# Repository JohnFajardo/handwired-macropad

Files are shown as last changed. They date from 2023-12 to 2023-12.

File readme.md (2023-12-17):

# Handwired Macropad

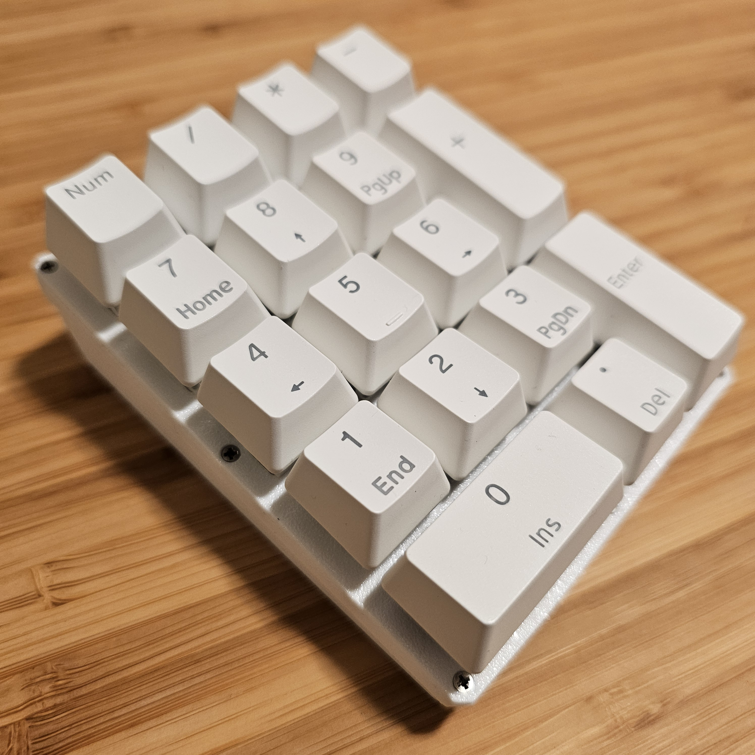
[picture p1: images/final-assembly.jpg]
final assembly


A quick handwired macropad I built for a coworker so that he could sample Box Jade switches.

## Bill of materials
* 17 Cherry style, plate-mounted switches, for example [Kailh Box Jades](https://www.amazon.com/gp/product/B0CBPRMP27/).

* 17 numpad keycaps salvaged from [el cheapo keycaps set](https://www.amazon.com/gp/product/B08K7FVZ5C/).

* 17 [1N4148 diodes](https://www.amazon.com/gp/product/B09PGJ1F9L/)

* 3 2u plate mounted [el cheapo stabilizers](https://www.amazon.com/gp/product/B096JQF1HH/).

* 10 M1.6 x 5mm self tapping, [flat-headed screws](https://www.mcmaster.com/90485A411/).

* 1 [Generic Pro micro RP2040 board](https://www.aliexpress.us/item/3256805943704472.html) or really any RP2040 based board, just be sure to use the same pins or edit the info.json file to match the ones you'll be using.

* Solder, wires and soldering iron.

## Pinout
* col0: GP27
* col1: GP20
* col2: GP29
* col3: GP11
* row0: GP10
* row1: GP0
* row2: GP2, the `+`  key is wired to the end of this row.
* row3: GP3
* row4: GP5, the `ENTER` key is wired to the end of this row.

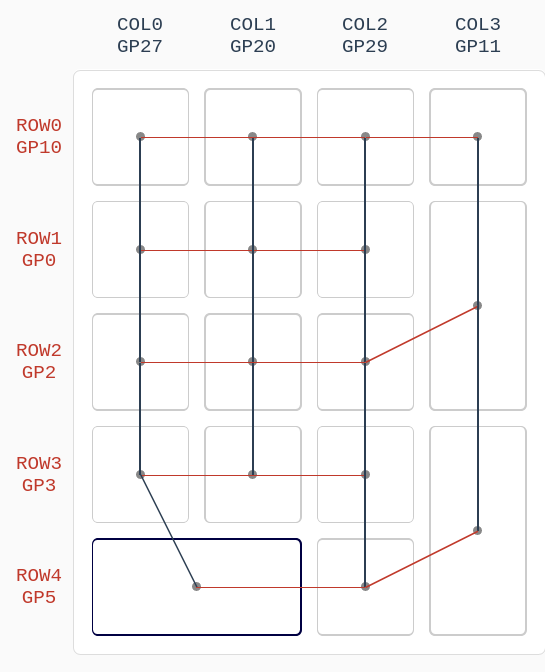
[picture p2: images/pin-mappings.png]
pin-mappings


Diodes are hooked into the rows, but if you solder them to the columns, remember to change `diode_direction` to `ROW2COL` in the `info.json` file.

## Firmware installation

* After [setting up your QMK environment](https://docs.qmk.fm/#/getting_started_build_tools), copy the `handwired_macropad` folder into the `keyboards` directory of your QMK installation.

* To check the layout, run:

```
qmk info -kb handwired_macropad -l 
```

Then to compile and flash in one go, just enter bootloader mode on your RP2040 and run:

```
qmk flash -kb handwired_macropad -km default
```

If you're new to QMK, check out their [Complete Newbs Guide](https://docs.qmk.fm/#/newbs).

## 3d printed case
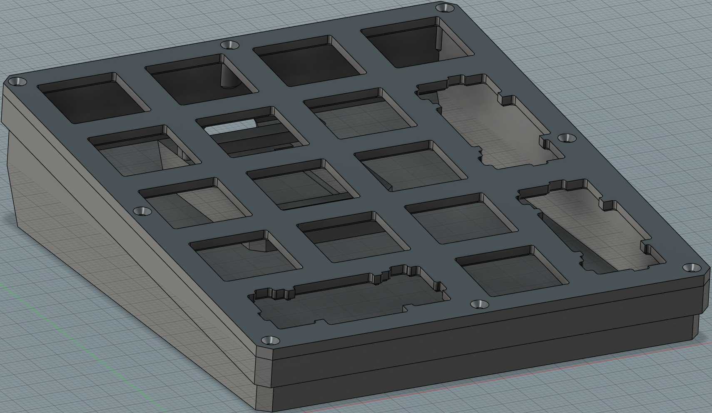
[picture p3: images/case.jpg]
case


A case model is provided for you to 3d print. It is recommended to print the plate with the top side facing the print surface for texture transfer, while supports are recommended for the case body.

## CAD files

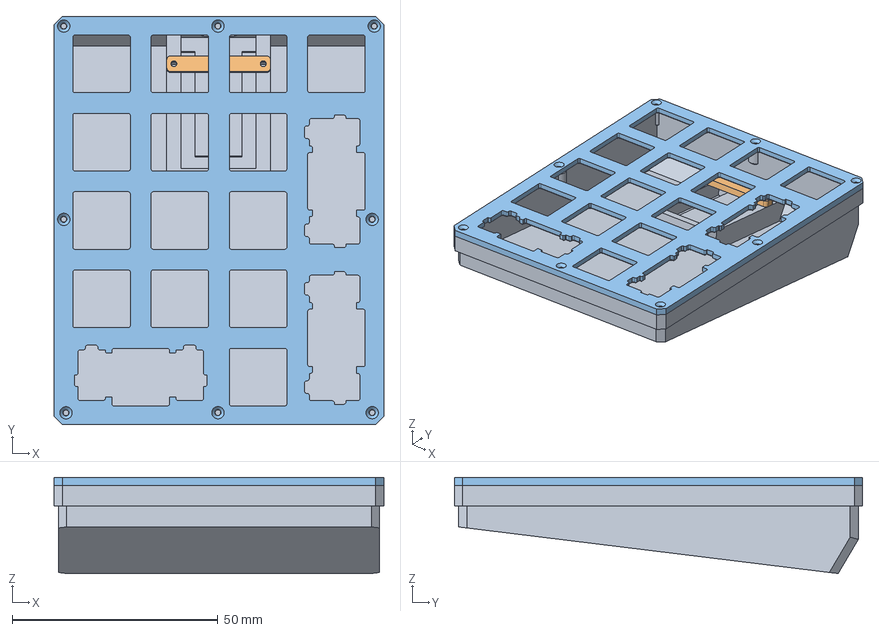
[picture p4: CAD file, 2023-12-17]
3d printed case/STEP/case.step
80.2 x 99.2 x 23.4 mm

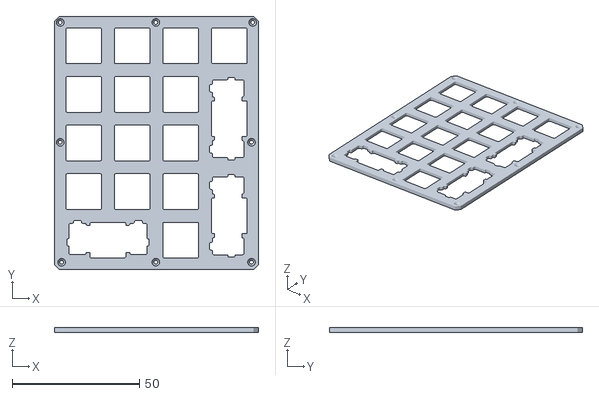
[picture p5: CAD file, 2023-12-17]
3d printed case/STL/Plate.stl
80.2 x 99.2 x 2.00

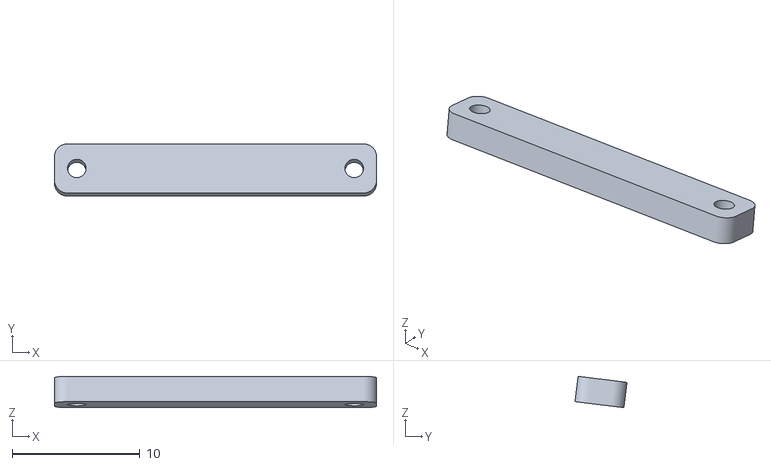
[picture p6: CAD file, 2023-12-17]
3d printed case/STL/Pro micro holder.stl
25.3 x 4.08 x 2.46

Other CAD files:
3d printed case/STL/Case.stl
